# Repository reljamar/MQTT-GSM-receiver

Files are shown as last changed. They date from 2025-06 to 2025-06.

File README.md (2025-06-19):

# MQTT-GSM-receiver
_A basic IoT device that connects to a mobile network and activates an output pin based on an MQTT message. The project is a work in progress_

## Purpose
This project is intended to be a basis of operation for a vast number of possible uses. The microcontroller connects to an MQTT topic and checks for key messages. When the appropriate message is received, an output pin is activated. With aditional periferal hardware, the device can be adapted to do various tasks. An important detail about the project is that unlike most IoT devices that connect via WiFi, this one connects via the mobile network, allowing it to be placed outside the range of WiFi networks: backyards, open fields, practically anywhere. The project also serves to prived an introduction to RF connectivity.

## Description
A device that uses the STM32L476RET6 microcontroller. The microcontroller communicates with a Quectel BC660K-GL GSM module using AT commands. The device subsribes to a topic on a server set up by the user, and an mobile phone application can send messages to that topic, which trigger the IoT device to activate an output signal. The device features a SIM card, EEPROM, and an input/ouput interface. Cybersecurity is of crucial importance for this application, however it is far from being developed at the time of writing. Currently an external antenna is used, but future iterations may include a built-in PCB antenna.

## Overview
- Quectel CB660K-GL GMS module for connectivity
- EEPROM for cybersecurity credentials
- Basis for projects with a well-defined use case

## System architecture
### Microcontroller
The system is based on an STM32L476RET6. They are readily available and powerful enough for encryption tasks. The microcontroller communicates vie UART using AT commands with the GSM module
### GSM Module
The module is Quectel's BC660K-GL. This is one of the cheapest GMS modules available, and even they are sometimes difficult to get by. The module is very easy to use with the AT commands, which makes development much faster. An important note is the antenna design, which is currently a weak spot in the project. Occasionally, the device simply loses its connection with the network. The module requires a SIM card. Some carriers offer IoT-specific services, which come with only data at a very slow rate, but are also very cheap on a monthly level.
### Antenna
The antenna is the weak link, and much care is needed when routing the antenna signal, even if an external antenna is used. Impedance control is very important here.

<p align="center">
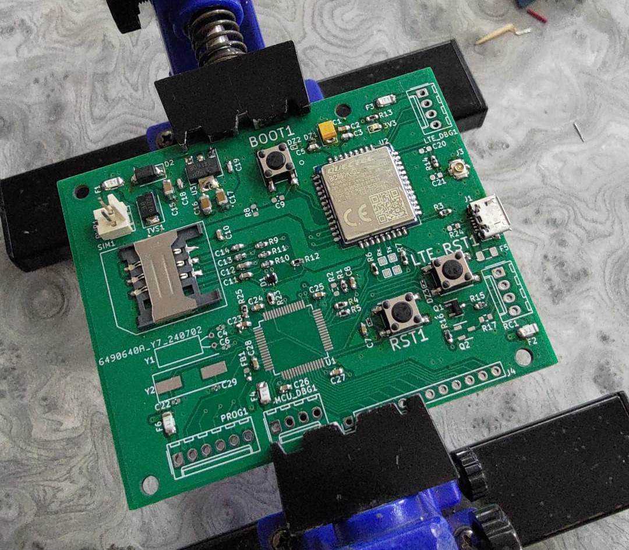
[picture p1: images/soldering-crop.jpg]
Soldering

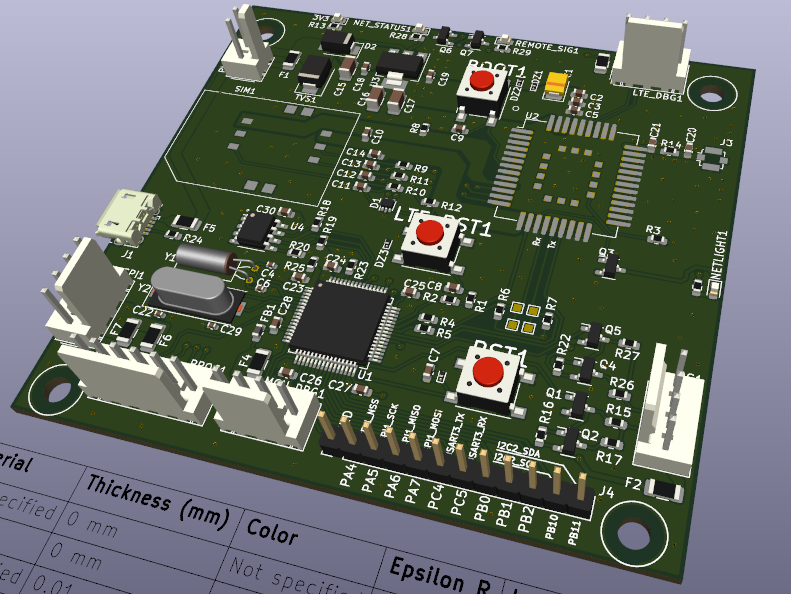
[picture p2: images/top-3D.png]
3D model

</p>

## Firmware
### Implemented features
- [x] Connecting to a GSM network
- [x] Subscribing to a topic
- [x] Error handling - lost connection triggers a reconnection attempt
- [x] Output pin control based on MQTT messages
### Planned features
- [ ] Cybersecurity
- [ ] Reporting/check-in feature
- [ ] Sending data from the input to the server

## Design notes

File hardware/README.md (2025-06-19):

This folder contains all of the hardware project files.
There is only one schematic page containing all the functions.
A BOM is attached since the antenna is not visible in the PCB project.

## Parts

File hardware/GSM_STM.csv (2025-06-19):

Source: | /
Date: | /
Tool: | Eeschema 7.0.9
Generator: | /
Component Count: | 109
Collated Components:
Item | Qty | Reference(s) | Value | Manufacturer | Manufacturer Part Number | Supplier | Supplier Part Number | TCR | Temperature Range | Termperature Range | Tolerance | Viewing Angle | Voltage Rating | Wavelength
1 | 4 | 3V3, NET_STATUS1, NETLIGHT1, REMOTE_SIG1 | LED GREEN | Würth Elektronik | 150060VS75000 | Digi-Key | 732-4980-1-ND |  |  |  |  | 140° |  | 570nm
2 | 2 | BOOT1, LTE_RST1 | SW_SPST | C&K | PTS645SL43SMTR92 LFS | Digi-Key | CKN10880CT-ND
3 | 1 | C1 | 100uF 6.3V TANT | KYOCERA AVX | TPSB107K006R0250 | Digi-Key | 478-3080-1-ND |  |  |  | 10%
4 | 8 | C2, C10, C24, C25, C26, C27, C28, C30 | 100nF 16V MLCC | Samsung | CL10B104KO8NNNC | Digi-Key | 1276-1005-1-ND |  |  |  | 10%
5 | 3 | C3, C18, C19 | 100pF 50V MLCC | Yageo | CC0603JRNPO9BN101 | Digi-Key | 311-1069-1-ND |  |  |  | 5%
6 | 2 | C4, C6 | 5pF 50V MLCC | YAGEO | CC0402BRNPO9BN5R0 | Digi-Key | 490-11334-1-ND |  |  |  | ±0.1pF
7 | 2 | C5, C9 | 22pF 50V MLCC | Yageo | CC0603JRNPO9BN220 | Digi-Key | 311-1062-1-ND |  |  |  | 5%
8 | 2 | C7, C8 | 100nF 16V MLCC | Samsung | CL10B104KO8NNNC | Digi-Key | 1276-1005-1-ND |  |  |  | 10%
9 | 4 | C11, C12, C13, C14 | 33pF 50V MLCC | Samsung Electro-Mechanics | CL10C330JB8NNNC | Digi-Key | 1276-1070-1-ND |  |  |  | 5%
10 | 3 | C15, C16, C17 | 10uF 50V MLCC | Samsung | CL31B106KBHNNNE | Digi-Key | 1276-6767-1-ND |  |  |  | 10%
11 | 2 | C20, C21 | 100pF 50V MLCC | Yageo | CC0603JRNPO9BN101 | Digi-Key | 311-1069-1-ND |  |  |  | 5%
12 | 2 | C22, C29 | 16pF 50V MLCC | Murata Electronics | GJM1555C1H160FB01J | Digi-Key | 490-GJM1555C1H160FB01JCT-ND |  |  |  | ±1%
13 | 1 | C23 | 1uF 16V MLCC | YAGEO | CC0603KRX7R7BB105 | Digi-Key | 311-1446-1-ND |  |  |  | 10%
14 | 1 | D1 | TVS 3V3RWV 4CH | Nexperia | PESD3V3L4UW | Digi-Key | 1727-5790-1-ND
15 | 1 | D2 | STKY 420mV 1A | Panjit | SS12L_R1_00001 | Digi-Key | 3757-SS12L_R1_00001CT-ND
16 | 4 | DZ1, DZ2, DZ3, DZ4 | TVS 5VRWV | Onsemi | ESD9X5.0ST5G | Digi-Key | ESD9X5.0ST5GOSCT-ND
17 | 6 | F1, F2, F3, F4, F6, F7 | FUSE 1A 63V | Bel Fuse Inc. | 0685T1000-01 | Digi-Key | -55°C ~ 125°C |  |  |  |  |  | 63V
18 | 1 | F5 | FUSE 1A 63V | Bel Fuse Inc. | 0685T1000-01 | Digi-Key | -55°C ~ 125°C |  |  |  |  |  | 63V
19 | 1 | FB1 | 600 Ohm @ 100 MHz | Pulse Electronics | BBBK00160808601Y00 | Digi-Key | 553-BBBK00160808601Y00CT-ND
20 | 1 | J1 | USB_B_Micro | Amphenol | 10118194-0001LF | Digi-Key | 609-4618-1-ND
21 | 1 | J3 | U.FL Coax | TE Connectivity | CONMHF1-SMD-T | Digi-Key | 343-CONMHF1-SMD-TCT-ND
22 | 1 | J4 | Conn_01x12
23 | 4 | LTE_DBG1, MCU_DBG1, NFC_SPI1, RC1 | Conn_01x04
24 | 1 | PROG1 | Conn_01x06
25 | 1 | PWR1 | Conn_01x02
26 | 5 | Q1, Q3, Q5, Q6, Q7 | NMOS 2N7002NXAKR | Nexperia | 2N7002NXAKR | Digi-Key | 1727-8643-1-ND
27 | 2 | Q2, Q4 | PMOS BSS84AK | Nexperia | BSS84AK | Digi-Key | 1727-BSS84AKVLCT-ND
28 | 8 | R1, R2, R3, R8, R14, R15, R25, R27 | 0R | Panasonic | ERJ-3GEY0R00V | Digi-Key | P0.0GCT-ND |  |  |  | Jumper
29 | 4 | R4, R5, R19, R20 | 1k | Panasonic | ERJ-3EKF1001V | Digi-Key | P1.00KHCT-ND |  |  |  | 1%
30 | 7 | R6, R7, R12, R16, R18, R22, R23 | 10k | Panasonic | ERJ-3EKF1002V | Digi-Key | P10.0KHCT-ND |  |  |  | 1%
31 | 3 | R9, R10, R11 | 22R | YAGEO | RC0603FR-0722RL | Digi-Key | 311-22.0HRCT-ND | ±100ppm/°C |  |  | 1%
32 | 4 | R13, R21, R28, R29 | 1k | Panasonic | ERJ-3EKF1001V | Digi-Key | P1.00KHCT-ND |  |  |  | 1%
33 | 2 | R17, R26 | 0R | Panasonic | ERJ-3GEY0R00V | Digi-Key | P0.0GCT-ND |  |  |  | Jumper
34 | 1 | R24 | 10k | Panasonic | ERJ-3EKF1002V | Digi-Key | P10.0KHCT-ND |  |  |  | 1%
35 | 1 | RST1 | SW_SPST | C&K | PTS645SL43SMTR92 LFS | Digi-Key | CKN10880CT-ND
36 | 1 | SIM1 | SIM_Card_6pin | CUI Devices | MSIM-10-B | Digi-Key | 2223-MSIM-10-BCT-ND
37 | 4 | TP_UART_RX1, TP_UART_RX2, TP_UART_TX1, TP_UART_TX2 | TestPoint
38 | 1 | TVS1 | TVS BID 12V STDOFF | Panjit | P6SMBJ12CA_R1_00001 | Digi-Key | 3757-P6SMBJ12CA_R1_00001CT-ND
39 | 1 | U1 | STM32L476RET6 | STMicroelectronics | STM32L476RET6TR | Digi-Key | 497-19381-1-ND
40 | 1 | U2 | BC660K-GL | Quectel | BC660K-GL | Digi-Key | 2958-BC660KGLAA-I03-SNASACT-ND |  | -35ºC ~ 75ºC
41 | 1 | U3 | VREG 3V3 | Diodes Inc | AZ1117IH-3.3TRG1 | Digi-Key | AZ1117IH-3.3TRG1DICT-ND
42 | 1 | U4 | 24C64x | Microchip | AT24C64D-SSHM-T | Digi-Key | AT24C64D-SSHM-TCT-ND |  |  | -40°C ~ 105°C
43 | 1 | Y1 | Crystal 32.768kHz | YIC | 32.768K12.5P2/DT38 | Digi-Key | 3155-32.768K12.5P2/DT38-ND
44 | 1 | Y2 | Crystal 8MHz | CTS-Frequency Controls | ATS080BSM-1E | Digi-Key | CTX1251CT-ND
45 | 1 | N/A | ANTENNA | Pulse Electronics | W3538B0150 | Digi-Key | 553-2585-ND

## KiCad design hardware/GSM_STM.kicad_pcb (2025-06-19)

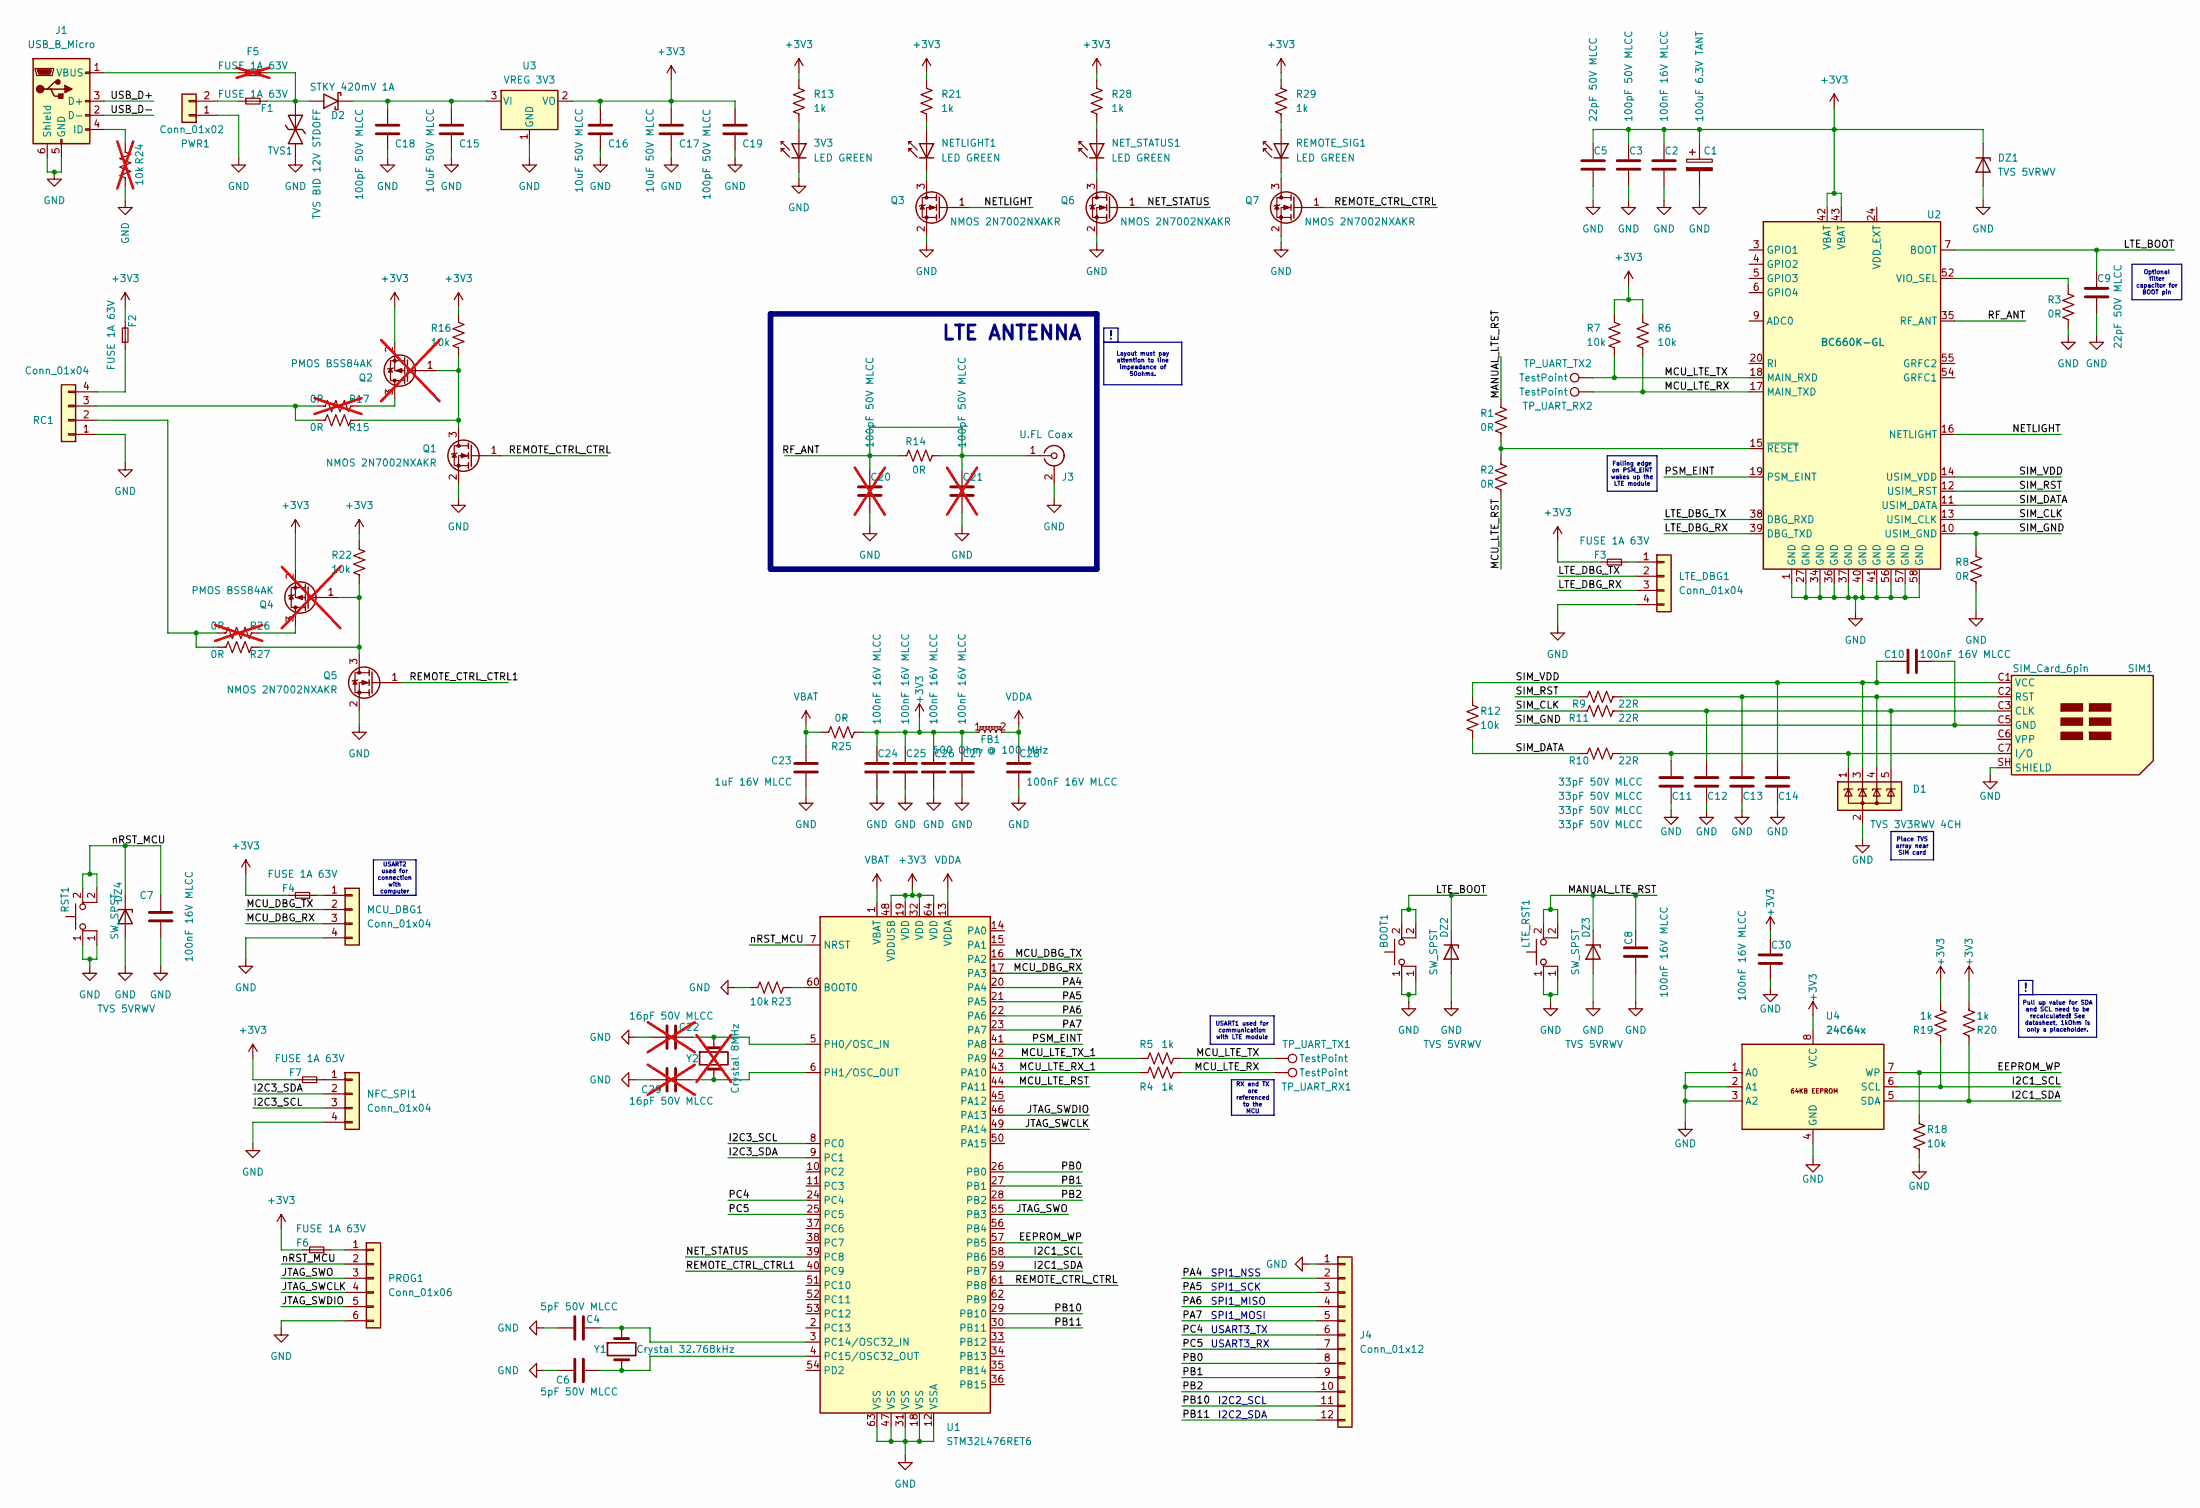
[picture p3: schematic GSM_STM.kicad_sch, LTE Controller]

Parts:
3V3: LED GREEN; LED_0603_1608Metric; Forward Voltage 2V; Manufacturer Part Number 150060VS75000
BOOT1: SW_SPST; SW_SPST_PTS645; Contact Rating 50mA @ 12V; Manufacturer Part Number PTS645SL43SMTR92 LFS
C1: 100uF 6.3V TANT; CP_EIA-3528-15_AVX-H; Tolerance 10%; Rated Voltage 6.3V; Manufacturer Part Number TPSB107K006R0250
C2, C7, C8, C10, C24, C25, C26, C27, C28, C30: 100nF 16V MLCC; C_0603_1608Metric; Tolerance 10%; Rated Voltage 16V; Manufacturer Part Number CL10B104KO8NNNC
C3, C18, C19: 100pF 50V MLCC; C_0603_1608Metric; Tolerance 5%; Rated Voltage 50V; Manufacturer Part Number CC0603JRNPO9BN101
C4, C6: 5pF 50V MLCC; C_0402_1005Metric; Tolerance ±0.1pF; Rated Voltage 50V; Manufacturer Part Number CC0402BRNPO9BN5R0
C5, C9: 22pF 50V MLCC; C_0603_1608Metric; Tolerance 5%; Rated Voltage 50V; Manufacturer Part Number CC0603JRNPO9BN220
C11, C12, C13, C14: 33pF 50V MLCC; C_0603_1608Metric; Tolerance 5%; Rated Voltage 50V; Manufacturer Part Number CL10C330JB8NNNC
C15, C16, C17: 10uF 50V MLCC; C_1206_3216Metric; Tolerance 10%; Rated Voltage 50V; Manufacturer Part Number CL31B106KBHNNNE
C20, C21: 100pF 50V MLCC; C_0603_1608Metric; Tolerance 5%; Rated Voltage 50V; Manufacturer Part Number CC0603JRNPO9BN101; not fitted
C22, C29: 16pF 50V MLCC; C_0402_1005Metric; Tolerance ±1%; Rated Voltage 50V; Manufacturer Part Number GJM1555C1H160FB01J; not fitted
C23: 1uF 16V MLCC; C_0603_1608Metric; Tolerance 10%; Rated Voltage 16V; Manufacturer Part Number CC0603KRX7R7BB105
D1: TVS 3V3RWV 4CH; SOT-665; Clamping Voltage 12V @ Ipp = 3A; Manufacturer Part Number PESD3V3L4UW
D2: STKY 420mV 1A; D_SMA; Forward Voltage 420mV @ 1A; Manufacturer Part Number SS12L_R1_00001
DZ1, DZ2, DZ3, DZ4: TVS 5VRWV; D_SOD-923; Clamping Voltage 12.3V; Manufacturer Part Number ESD9X5.0ST5G
F1, F2, F3, F4, F6, F7: FUSE 1A 63V; Fuse_1206_3216Metric; Current Rating 1A; Voltage Rating 63V; Manufacturer Part Number 0685T1000-01
F5: FUSE 1A 63V; Fuse_1206_3216Metric; Current Rating 1A; Voltage Rating 63V; Manufacturer Part Number 0685T1000-01; not fitted
FB1: 600 Ohm @ 100 MHz; L_0603_1608Metric; Current Rating (Max) 300mA; Manufacturer Part Number BBBK00160808601Y00
J1: USB_B_Micro; USB_Micro-B_Amphenol_10118194_Horizontal; Manufacturer Part Number 10118194-0001LF
J3: U.FL Coax; U.FL_Molex_MCRF_73412-0110_Vertical; Manufacturer Part Number CONMHF1-SMD-T
J4: Conn_01x12; PinHeader_1x12_P2.54mm_Vertical
LTE_DBG1: Conn_01x04; Molex_KK-254_AE-6410-04A_1x04_P2.54mm_Vertical
LTE_RST1: SW_SPST; SW_SPST_PTS645; Contact Rating 50mA @ 12V; Manufacturer Part Number PTS645SL43SMTR92 LFS
MCU_DBG1: Conn_01x04; Molex_KK-254_AE-6410-04A_1x04_P2.54mm_Vertical
NETLIGHT1: LED GREEN; LED_0603_1608Metric; Forward Voltage 2V; Manufacturer Part Number 150060VS75000
NET_STATUS1: LED GREEN; LED_0603_1608Metric; Forward Voltage 2V; Manufacturer Part Number 150060VS75000
NFC_SPI1: Conn_01x04; Molex_KK-254_AE-6410-04A_1x04_P2.54mm_Vertical
PROG1: Conn_01x06; Molex_KK-254_AE-6410-06A_1x06_P2.54mm_Vertical
PWR1: Conn_01x02; Molex_KK-254_AE-6410-02A_1x02_P2.54mm_Vertical
Q1, Q3, Q5, Q6, Q7: NMOS 2N7002NXAKR; SOT-23-3; Manufacturer Part Number 2N7002NXAKR
Q2, Q4: PMOS BSS84AK; SOT-23-3; Manufacturer Part Number BSS84AK; not fitted
R1, R2, R3, R8, R14, R15, R25, R27: 0R; R_0603_1608Metric; Tolerance Jumper; Power Rating 100mW; Manufacturer Part Number ERJ-3GEY0R00V
R4, R5, R13, R19, R20, R21, R28, R29: 1k; R_0603_1608Metric; Tolerance 1%; Power Rating 100mW; Manufacturer Part Number ERJ-3EKF1001V
R6, R7, R12, R16, R18, R22, R23: 10k; R_0603_1608Metric; Tolerance 1%; Power Rating 100mW; Manufacturer Part Number ERJ-3EKF1002V
R9, R10, R11: 22R; R_0603_1608Metric; Tolerance 1%; Power Rating 100mW; Manufacturer Part Number RC0603FR-0722RL
R17, R26: 0R; R_0603_1608Metric; Tolerance Jumper; Power Rating 100mW; Manufacturer Part Number ERJ-3GEY0R00V; not fitted
R24: 10k; R_0603_1608Metric; Tolerance 1%; Power Rating 100mW; Manufacturer Part Number ERJ-3EKF1002V; not fitted
RC1: Conn_01x04; Molex_KK-254_AE-6410-04A_1x04_P2.54mm_Vertical
REMOTE_SIG1: LED GREEN; LED_0603_1608Metric; Forward Voltage 2V; Manufacturer Part Number 150060VS75000
RST1: SW_SPST; SW_SPST_PTS645; Contact Rating 50mA @ 12V; Manufacturer Part Number PTS645SL43SMTR92 LFS
SIM1: SIM_Card_6pin; CUI_MICRO_SIM; Manufacturer Part Number MSIM-10-B
TP_UART_RX1, TP_UART_RX2: TestPoint; TestPoint_Pad_1.0x1.0mm
TP_UART_TX1, TP_UART_TX2: TestPoint; TestPoint_Pad_1.0x1.0mm
TVS1: TVS BID 12V STDOFF; D_SMB; Breakdown Voltage 13.3V; Clamping Voltage 19V; Manufacturer Part Number P6SMBJ12CA_R1_00001
U1: STM32L476RET6; LQFP-64_10x10mm_P0.5mm; Manufacturer Part Number STM32L476RET6TR
U2: BC660K-GL; Quectel_BC66; Manufacturer Part Number BC660K-GL
U3: VREG 3V3; SOT-223-3_TabPin2; Output Voltage 3.3V; Dropout Voltage 1.2V; Manufacturer Part Number AZ1117IH-3.3TRG1
U4: 24C64x; SOIC-8_3.9x4.9mm_P1.27mm; Manufacturer Part Number AT24C64D-SSHM-T
Y1: Crystal 32.768kHz; Crystal_C38-LF_D3.0mm_L8.0mm_Horizontal; Frequency Tolerance ±20ppm; Manufacturer Part Number 32.768K12.5P2/DT38
Y2: Crystal 8MHz; Crystal_SMD_HC49-SD; Frequency Tolerance ±30ppm; Manufacturer Part Number ATS080BSM-1E; not fitted

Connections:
+3V3: C1.1, C2.1, C3.1, C5.1, C16.1, C17.1, C19.2, C24.1, C25.1, C26.1, C27.1, C30.1, DZ1.1 (K), F2.2, F3.2, F4.2, F6.2, F7.2, FB1.1, Q2.2 (S), Q4.2 (S), R6.1, R7.1, R13.1, R16.1, R19.1, R20.1, R21.1, R22.1, R25.2, R28.1, R29.1, U1.19 (VDD), U1.32 (VDD), U1.48 (VDDUSB), U1.64 (VDD), U2.42 (VBAT), U2.43 (VBAT), U3.2 (VO), U4.8 (VCC)
/EEPROM_WP: R18.1, U1.57 (PB5), U4.7 (WP)
/I2C1_SCL: R19.2, U1.58 (PB6), U4.6 (SCL)
/I2C1_SDA: R20.2, U1.59 (PB7), U4.5 (SDA)
/I2C3_SCL: NFC_SPI1.3, U1.8 (PC0)
/I2C3_SDA: NFC_SPI1.2, U1.9 (PC1)
/JTAG_SWCLK: PROG1.4, U1.49 (PA14)
/JTAG_SWDIO: PROG1.5, U1.46 (PA13)
/JTAG_SWO: PROG1.3, U1.55 (PB3)
/LTE_BOOT: BOOT1.2, C9.1, DZ2.1 (K), U2.7 (BOOT)
/LTE_DBG_RX: LTE_DBG1.3, U2.39 (DBG_TXD)
/LTE_DBG_TX: LTE_DBG1.2, U2.38 (DBG_RXD)
/MANUAL_LTE_RST: C8.2, DZ3.1 (K), LTE_RST1.2, R1.1
/MCU_DBG_RX: MCU_DBG1.3, U1.17 (PA3)
/MCU_DBG_TX: MCU_DBG1.2, U1.16 (PA2)
/MCU_LTE_RST: R2.2, U1.44 (PA11)
/MCU_LTE_RX: R4.1, R6.2, TP_UART_RX1.1, TP_UART_RX2.1, U2.17 (MAIN_TXD)
/MCU_LTE_RX_1: R4.2, U1.43 (PA10)
/MCU_LTE_TX: R5.1, R7.2, TP_UART_TX1.1, TP_UART_TX2.1, U2.18 (MAIN_RXD)
/MCU_LTE_TX_1: R5.2, U1.42 (PA9)
/NETLIGHT: Q3.1 (G), U2.16 (NETLIGHT)
/NET_STATUS: Q6.1 (G), U1.39 (PC8)
/PA4: J4.2, U1.20 (PA4)
/PA5: J4.3, U1.21 (PA5)
/PA6: J4.4, U1.22 (PA6)
/PA7: J4.5, U1.23 (PA7)
/PB0: J4.8, U1.26 (PB0)
/PB1: J4.9, U1.27 (PB1)
/PB2: J4.10, U1.28 (PB2)
/PB10: J4.11, U1.29 (PB10)
/PB11: J4.12, U1.30 (PB11)
/PC4: J4.6, U1.24 (PC4)
/PC5: J4.7, U1.25 (PC5)
/PSM_EINT: U1.41 (PA8), U2.19 (PSM_EINT)
/REMOTE_CTRL_CTRL: Q1.1 (G), Q7.1 (G), U1.61 (PB8)
/REMOTE_CTRL_CTRL1: Q5.1 (G), U1.40 (PC9)
/RF_ANT: C20.1, C21.1, J3.1 (In), R14.1, R14.2, U2.35 (RF_ANT)
/SIM_CLK: R11.1, U2.13 (USIM_CLK)
/SIM_DATA: R10.1, R12.2, U2.11 (USIM_DATA)
/SIM_GND: C10.2, R8.1, SIM1.C5 (GND), U2.10 (USIM_GND)
/SIM_RST: R9.1, U2.12 (USIM_RST)
/SIM_VDD: C10.1, C14.1, D1.3 (K), R12.1, SIM1.C1 (VCC), U2.14 (USIM_VDD)
/USB_D+: J1.3 (D+)
/USB_D-: J1.2 (D-)
/nRST_MCU: C7.2, DZ4.1 (K), PROG1.2, RST1.2, U1.7 (NRST)
GND: 3V3.1 (K), BOOT1.1, C1.2, C2.2, C3.2, C4.1, C5.2, C6.1, C7.1, C8.1, C9.2, C11.2, C12.2, C13.2, C14.2, C15.2, C16.2, C17.2, C18.1, C19.1, C20.2, C21.2, C22.1, C23.2, C24.2, C25.2, C26.2, C27.2, C28.2, C29.1, C30.2, D1.2 (A), DZ1.2 (A), DZ2.2 (A), DZ3.2 (A), DZ4.2 (A), J1.5 (GND), J1.6 (Shield), J3.2 (Ext), J4.1, LTE_DBG1.4, LTE_RST1.1, MCU_DBG1.4, NFC_SPI1.4, PROG1.6, PWR1.1, Q1.2 (S), Q3.2 (S), Q5.2 (S), Q6.2 (S), Q7.2 (S), R3.2, R8.2, R18.2, R23.2, R24.2, RC1.1, RST1.1, SIM1.SH (SHIELD), TVS1.1 (K), U1.12 (VSSA), U1.18 (VSS), U1.31 (VSS), U1.47 (VSS), U1.63 (VSS), U2.1 (GND), U2.27 (GND), U2.34 (GND), U2.36 (GND), U2.37 (GND), U2.40 (GND), U2.41 (GND), U2.56 (GND), U2.57 (GND), U2.58 (GND), U3.1 (GND), U4.1 (A0), U4.2 (A1), U4.3 (A2), U4.4 (GND)
unnamed: 3V3.2 (A), R13.2
unnamed: D2.2 (A), F1.2, F5.2, TVS1.2 (A)
unnamed: C15.1, C18.2, D2.1 (K), U3.3 (VI)
unnamed: J1.4 (ID), R24.1
unnamed: F5.1, J1.1 (VBUS)
unnamed: F3.1, LTE_DBG1.1
unnamed: F4.1, MCU_DBG1.1
unnamed: NETLIGHT1.2 (A), R21.2
unnamed: NETLIGHT1.1 (K), Q3.3 (D)
unnamed: NET_STATUS1.2 (A), R28.2
unnamed: NET_STATUS1.1 (K), Q6.3 (D)
unnamed: F7.1, NFC_SPI1.1
unnamed: F6.1, PROG1.1
unnamed: F1.1, PWR1.2
unnamed: Q1.3 (D), Q2.1 (G), R15.2, R16.2
unnamed: Q2.3 (D), R17.2
unnamed: Q4.3 (D), R26.2
unnamed: Q4.1 (G), Q5.3 (D), R22.2, R27.2
unnamed: Q7.3 (D), REMOTE_SIG1.1 (K)
unnamed: R26.1, R27.1, RC1.2
unnamed: R15.1, R17.1, RC1.3
unnamed: F2.1, RC1.4
unnamed: R29.2, REMOTE_SIG1.2 (A)
unnamed: C12.1, D1.5 (K), R11.2, SIM1.C3 (CLK)
unnamed: C11.1, D1.1 (K), R10.2, SIM1.C7 (I/O)
unnamed: C13.1, D1.4 (K), R9.2, SIM1.C2 (RST)
unnamed: R23.1, U1.60 (BOOT0)
unnamed: C4.2, U1.3 (PC14/OSC32_IN), Y1.1
unnamed: C6.2, U1.4 (PC15/OSC32_OUT), Y1.2
unnamed: C22.2, U1.5 (PH0/OSC_IN), Y2.1
unnamed: C29.2, U1.6 (PH1/OSC_OUT), Y2.2
unnamed: R3.1, U2.52 (VIO_SEL)
unnamed: R1.2, R2.1, U2.15 (~RESET)
VBAT: C23.1, R25.1, U1.1 (VBAT)
VDDA: C28.1, FB1.2, U1.13 (VDDA)

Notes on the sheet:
Layout must pay attention to line impeadance of 50ohms.
Pull up value for SDA and SCL need to be recalculated! See datasheet, 1kOhm is only a placeholder.
USART2 used for connection with computer
Optional filter capacitor for BOOT pin
Place TVS array near SIM card
RX and TX are referenced to the MCU
Falling edge on PSM_EINT wakes up the LTE module
USART1 used for communication with LTE module
USART3_RX
USART3_TX
SPI1_MOSI
SPI1_NSS
SPI1_SCK
SPI1_MISO
I2C2_SCL
I2C2_SDA
LTE ANTENNA

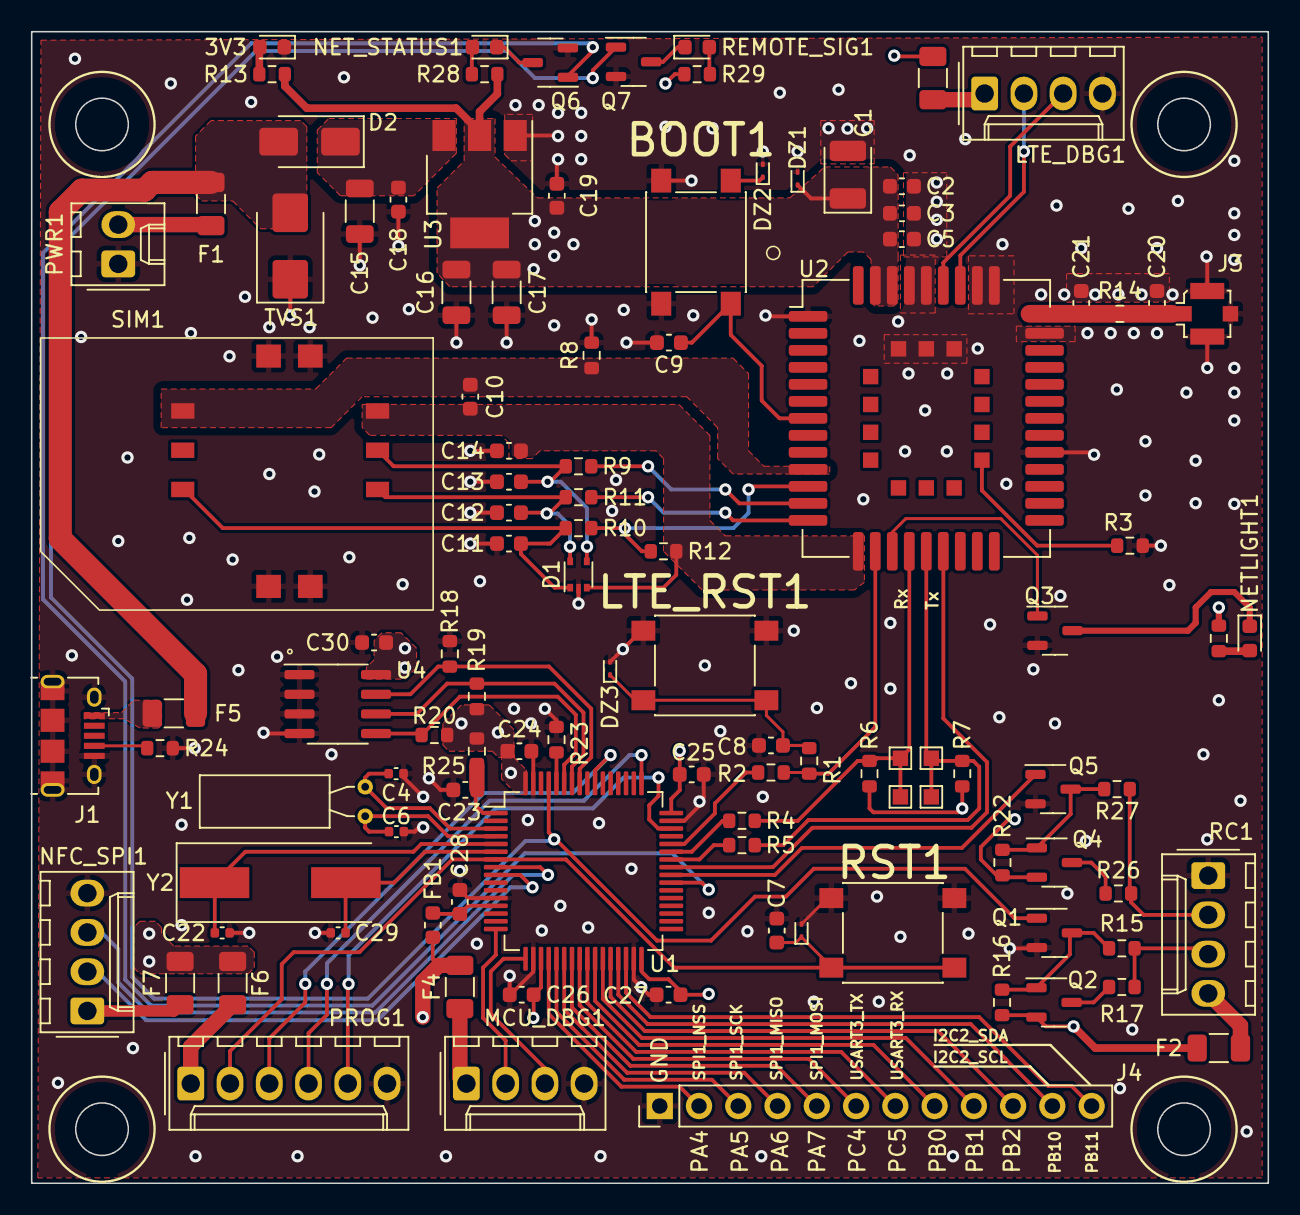
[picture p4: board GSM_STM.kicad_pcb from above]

Board: 4 copper layers, 80.0 x 74.5 mm, 108 parts (0 on the bottom side), 79 nets.

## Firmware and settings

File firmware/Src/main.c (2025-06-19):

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
/* Includes ------------------------------------------------------------------*/
#include "main.h"

/* USER CODE BEGIN PD */
#define BUFFER_SIZE 128
#define COMMAND_COUNT 9
/* USER CODE END PD */

RTC_HandleTypeDef hrtc;

UART_HandleTypeDef huart1;
UART_HandleTypeDef huart2;

/* USER CODE BEGIN PV */
volatile char commandStrings[COMMAND_COUNT][BUFFER_SIZE] = {
	"AT",
	"ATE0",
	"AT+QSCLK=0",
	"AT+COPS=1,2,\"22005\"",
  "AT+CREG=2",
	"AT+QMTCFG=\"keepalive\",0,3",
	"AT+QMTOPEN=0,\"xx.xxx.xxx.xxx\",xxxx",
	"AT+QMTCONN=0,\"ID\",\"USER\",\"PASS\"",
	"AT+QMTSUB=0,1,\"TOPIC\",2"
};
volatile char responsStrings[COMMAND_COUNT][BUFFER_SIZE] = {
	"OK",
  "OK",
	"OK",
  "OK",
  "OK",
  "OK",
	"OK\r\n\r\n+QMTOPEN: 0,0",
	"OK\r\n\r\n+QMTCONN: 0,0,0",
	"OK\r\n\r\n+QMTSUB: 0,1,0,2"
};
int sub_flag = 0;
/* USER CODE END PV */

void SystemClock_Config(void);
static void MX_GPIO_Init(void);
static void MX_USART2_UART_Init(void);
static void MX_USART1_UART_Init(void);
static void MX_RTC_Init(void);
void send_AT_command(char *command) ;
int wait_for_response(char *response);
int wait_for_action(void);
/**
  * @brief  The application entry point.
  * @retval int
  */
int main(void)
{

  /* MCU Configuration--------------------------------------------------------*/

  /* Reset of all peripherals, Initializes the Flash interface and the Systick. */
  HAL_Init();

  /* Configure the system clock */
  SystemClock_Config();

  /* Initialize all configured peripherals */
  MX_GPIO_Init();
  MX_USART2_UART_Init();
  MX_USART1_UART_Init();
  //MX_RTC_Init();
  /* USER CODE BEGIN 2 */
  int i = 0;
  int restart_counter = 0;
  //HAL_Delay(1000);
  send_AT_command("AT");
  /* USER CODE END 2 */

  /* Infinite loop */
  /* USER CODE BEGIN WHILE */
  while (1)
  {
	  while(i<COMMAND_COUNT){
	  		  // Send AT command and wait for proper response
	  		  if (wait_for_response(responsStrings[i])) {
	  			  // Send another command after receiving proper response
	  			  i++;
	  			  if(i==COMMAND_COUNT)
	  				  break;
	  			  send_AT_command(commandStrings[i]);
	  		  }
	  		  else{
	  			  //if the adequate response was not received restart everything
	  			  if(restart_counter >= 2){
	  				  restart_counter = 0;
	  				  i=0;
					  HAL_GPIO_WritePin(GPIOA, GPIO_PIN_11, GPIO_PIN_RESET);
					  HAL_Delay(100);
					  HAL_GPIO_WritePin(GPIOA, GPIO_PIN_11, GPIO_PIN_SET);
					  send_AT_command("AT");
	  			  }
	  			  else{
	  				restart_counter++;
	  				send_AT_command(commandStrings[i]);
	  			  }

	  		  }

	  }
	  int result = wait_for_action();
	  HAL_GPIO_WritePin(GPIOB, GPIO_PIN_8, GPIO_PIN_RESET);
	  if(result == 1){
		  HAL_GPIO_WritePin(GPIOB, GPIO_PIN_8, GPIO_PIN_SET);
	  }
	  else if(result == 2 || result == 3){
		  i = 0;
		  HAL_GPIO_WritePin(GPIOA, GPIO_PIN_11, GPIO_PIN_RESET);
		  HAL_Delay(100);
		  HAL_GPIO_WritePin(GPIOA, GPIO_PIN_11, GPIO_PIN_SET);
		  send_AT_command("AT");
	  }


  }

}



void send_AT_command(char *command) {
    char command_with_termination[BUFFER_SIZE];
    memset(command_with_termination, 0, BUFFER_SIZE);
    snprintf(command_with_termination, BUFFER_SIZE, "%s\r\n", command);
    HAL_UART_Transmit(&huart1, (uint8_t*)command_with_termination, strlen(command_with_termination), HAL_MAX_DELAY);
    snprintf(command_with_termination, BUFFER_SIZE, "Me: %s\r\n", command);
    HAL_UART_Transmit(&huart2, (uint8_t*)command_with_termination, strlen(command_with_termination), HAL_MAX_DELAY); //send a copy of the command also to PC

}

int wait_for_response(char *response) {
    char rx_buffer[BUFFER_SIZE];
    memset(rx_buffer, 0, BUFFER_SIZE);
    HAL_UART_Receive(&huart1, (uint8_t*)rx_buffer, BUFFER_SIZE, 1500);

    char command_with_termination[BUFFER_SIZE];
    snprintf(command_with_termination, BUFFER_SIZE, "Quecky: %s", rx_buffer);
    HAL_UART_Transmit(&huart2, (uint8_t*)command_with_termination, strlen(command_with_termination), HAL_MAX_DELAY); //send a copy of the command also to PC


    if (strstr(rx_buffer, response) != NULL) {
        return 1; // OK received
    }
    return 0; // OK not received
}

int wait_for_action(void) {
    char rx_buffer[BUFFER_SIZE];
    memset(rx_buffer, 0, BUFFER_SIZE);
    HAL_UART_Receive(&huart1, (uint8_t*)rx_buffer, BUFFER_SIZE, 1500);


    char command_with_termination[BUFFER_SIZE];
    memset(command_with_termination, 0, BUFFER_SIZE);
    snprintf(command_with_termination, BUFFER_SIZE, "Quecky: %s", rx_buffer);
    HAL_UART_Transmit(&huart2, (uint8_t*)command_with_termination, strlen(command_with_termination), HAL_MAX_DELAY); //send a copy of the command also to PC



    if(strstr(rx_buffer,"\"MESSAGE_KEYWORD\"") != NULL){
    	return 1;
    }
    else if(strcmp(rx_buffer, "\r\n+CREG: 1\r\n") != 0 && strcmp(rx_buffer, "") != 0)
    	return 3; // doslo je do greske

    return 0; // OK not received
}

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


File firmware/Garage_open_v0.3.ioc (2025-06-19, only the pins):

Mcu.UserName=STM32L476RGTx
PA10.Signal=USART1_RX
PA11.Signal=GPIO_Output
PA2.GPIO_Label=USART_TX
PA2.Signal=USART2_TX
PA3.GPIO_Label=USART_RX
PA3.Signal=USART2_RX
PA5.GPIO_Label=LD2 [green Led]
PA5.Signal=GPIO_Output
PA9.Signal=USART1_TX
PB8.Signal=GPIO_Output
PC13.GPIO_Label=B1 [Blue PushButton]
PC13.Signal=GPXTI13

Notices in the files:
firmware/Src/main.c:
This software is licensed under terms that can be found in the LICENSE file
